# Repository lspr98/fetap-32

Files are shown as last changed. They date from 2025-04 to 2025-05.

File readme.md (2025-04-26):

# FeTAp-32

<picture>
  <source srcset="doc/images/fetap32-logo-text-black.svg" media="(prefers-color-scheme: light)"/>
  <source srcset="doc/images/fetap32-logo-text-white.svg"  media="(prefers-color-scheme: dark)"/>
  
</picture>

## Description
FeTAp-32 is an open-source project that turns an old FeTAp 611-2 (Fernsprechtischapparat) into a voice assistant device through an ESP32-C3 and [esphome](https://esphome.io/).

## Features
- Fully functional rotary dial with customizable automations for each digit
- Power delivery through USB-C, network connectivity through Wifi 2.4 GHz
- Enhanced privacy as microphone is only active if handset is lifted-up
- No wake-word detection required, the assistant is started when the handset is picked up
- Modular and customizable through esphome

<p align="middle">
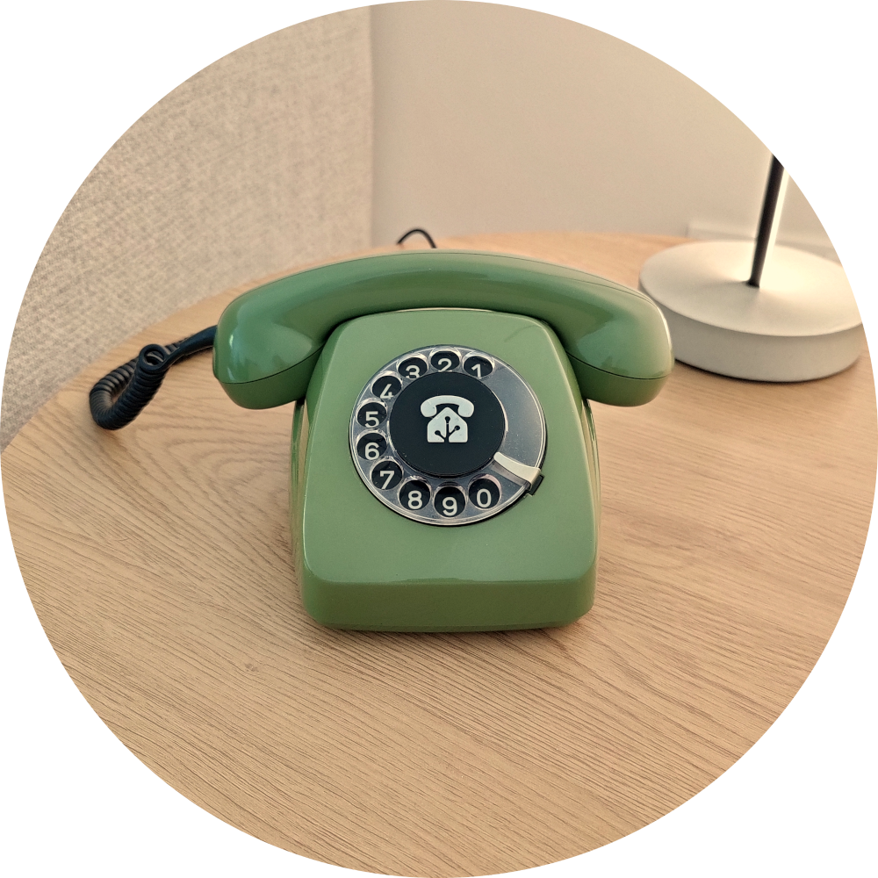
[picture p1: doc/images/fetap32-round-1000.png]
  
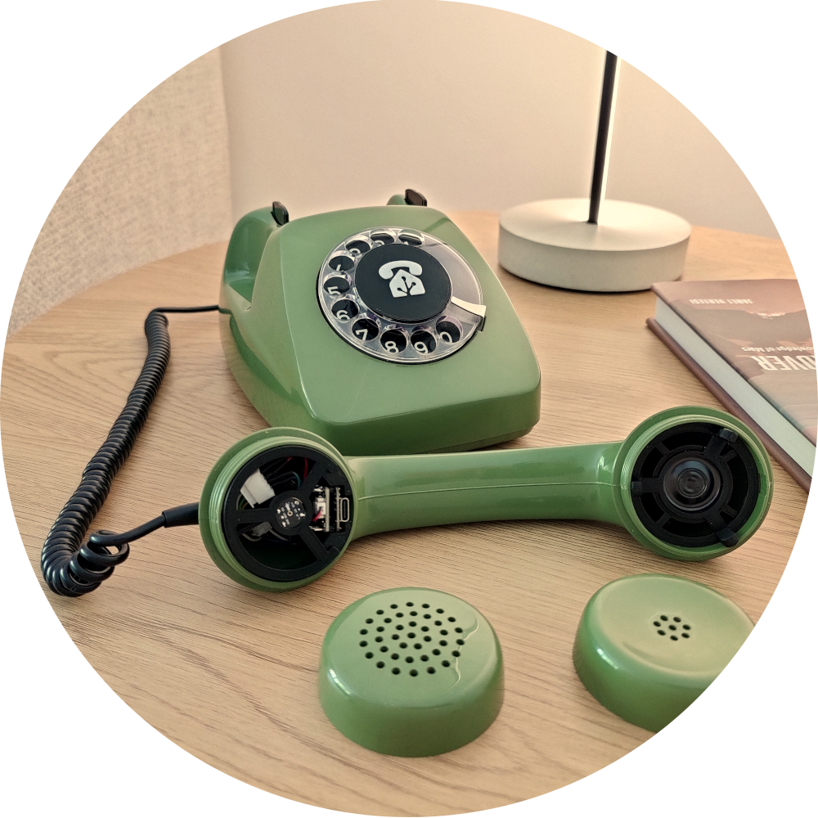
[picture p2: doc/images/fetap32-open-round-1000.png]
   
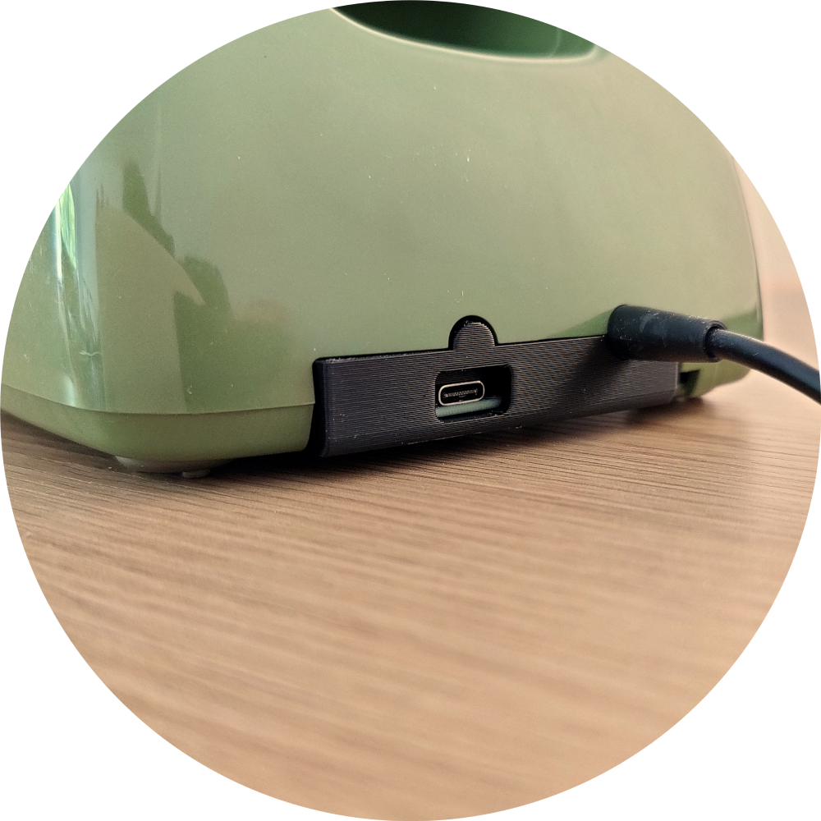
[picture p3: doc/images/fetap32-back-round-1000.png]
  
</p>

## Building instructions (Hardware and Software)
The manual can be found [here](doc/manual/manual.pdf)

## Disclaimer and warning
Recreating this project involves handling dangerous things like soldering irons and 3D-printers. For legal reasons, handling these things should only be done by an expert. I am not responsible for any damage to you, your telephone or your surrounding. Read through the complete manual to decide if you feel comfortable building the project.

## Required Tools
- 3D-printer
- soldering iron
- connector crimping kit (see BoM, optional but recommended)

## Bill of Materials (BoM)
The following items are necessary to build the FeTAp-32. Items marked with a (*) at the beginning do not need to be the exact listed item but may be replaced with something else. Sourcing links are included for people based in germany (those are the shops where I got the items from).

|Item|Amount|Description|Comment|Sourcing (DE)|
|---|---|---|---|---|
|FeTAp 611-2|1|the telephone|Commonly found on kleinanzeigen for cheap. Doesn't have to be functional as the ESP will replace the PCB.|-|
|Seeed Xiao ESP32C3|1|Modem and microcontroller|-|[Botland](https://botland.de/wifi-und-bt-module-esp32/21859-seeed-xiao-esp32-c3-wlan-bluetooth-seeedstudio-113991054.html) [Reichelt](https://www.reichelt.de/de/de/shop/produkt/xiao_esp32c3_wifi_bt-358356?search=esp32c3&)|
|Adafruit USB Type-C Breakout Board (ADA4090)|1|port for power over USB-C|-|[Berrybase](https://www.berrybase.de/adafruit-usb-type-c-breakout-board-downstream-verbindung)|
|Stranded Wire|~2m|wire to connect the components with each other|I recommend stranded wires and getting multiple colors to make it easier. The wires I used were multi-stranded with 0.14mm^2 diameter (approx. 25 AWG)|[Reichelt](https://www.reichelt.de/de/de/shop/produkt/kupferlitze_isoliert_10_m_1_x_0_14_mm_blau-10292)|
|INMP441 MEMS Microphone|1|digital microphone to capture voice commands|Optional, if you don't want voice assistant capabilities (e.g. only want to use the rotary dial)|[Berrybase](https://www.berrybase.de/inmp441-mems-omnidirektionales-mikrofonmodul-i2s-interface)|
|*Adafruit I2S Amplifier (ADA5769)|1|amplifier for the handset speaker|Optional, if you don't need audio output. There is also a version without SD-Card slot (ADA5770) that should also work.|[Botland](https://botland.de/mp3-wav-ogg-midi-player/23827-audio-bff-add-on-3w-i2s-audio-verstarker-modul-fur-qt-py-und-xiao-adafruit-5769.html) [Berrybase](https://www.berrybase.de/adafruit-audio-add-on-fuer-qt-py-und-xiao)|
|YD27 0.5W 8 Ohm speaker|1|speaker for audio feedback from voice assistant|Optional, if you don't need audio output.|[Botland](https://botland.de/analoge-lautsprecher/3471-lautsprecher-yd27-05w-8ohm-27x5mm-5903351245876.html)|
|Adafruit Molex PicoBlade cable|1|connector and cable for speaker and I2S amplifier|Optional, if you don't need audio output.|[Berrybase](https://www.berrybase.de/adafruit-molex-picoblade-kabel-2-polig-200mm-1.25mm-pitch-reibungsverriegelung)|
|*JST-XH 5-Pin Male and Female connectors|1|connector for microphone and esp|Optional, if you don't want to use a microphone or directly solder the wires together|[Amazon](https://www.amazon.de/SOMELINE%C2%AE-Crimpzange-Stecker-JST-XH-EI-Serie/dp/B0C8N8JBDC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)|
|*JST-XH 4-Pin Male and Female connectors|2|connectors for handset, housing and esp|Optional, if you want to directly solder the wires together|see above|
|*JST-XH 2-Pin Male and Female connectors|3|connectors for power, rotary-dial-sensor and handset-sensor|Optional, if you don't want to use a microphone or directly solder the wires together|see above|

Apart from the items listed above, you will need common consumables like shrink tubing, solder and 3D-printer filament.

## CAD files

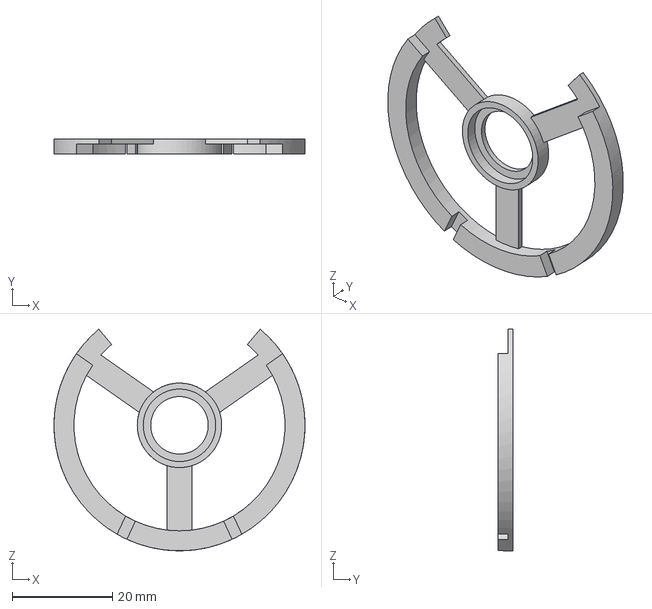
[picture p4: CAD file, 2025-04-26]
hardware/Esp_Brace v1.step
50.2 x 3.00 x 44.3 mm

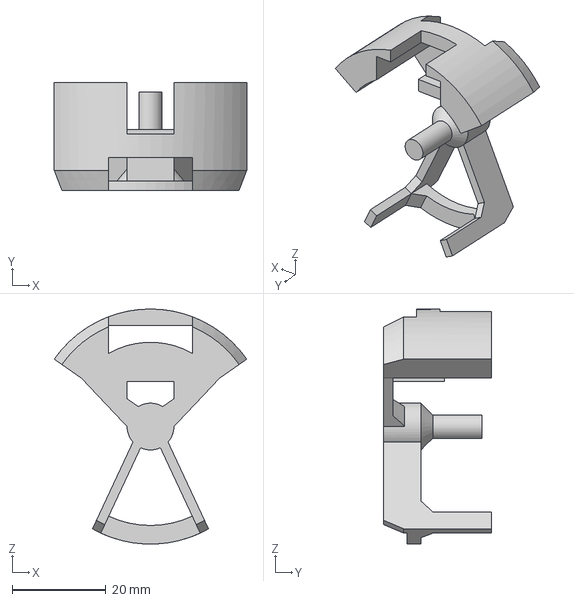
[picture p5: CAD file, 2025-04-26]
hardware/Esp_Insert v1.step
41.1 x 23.0 x 50.2 mm

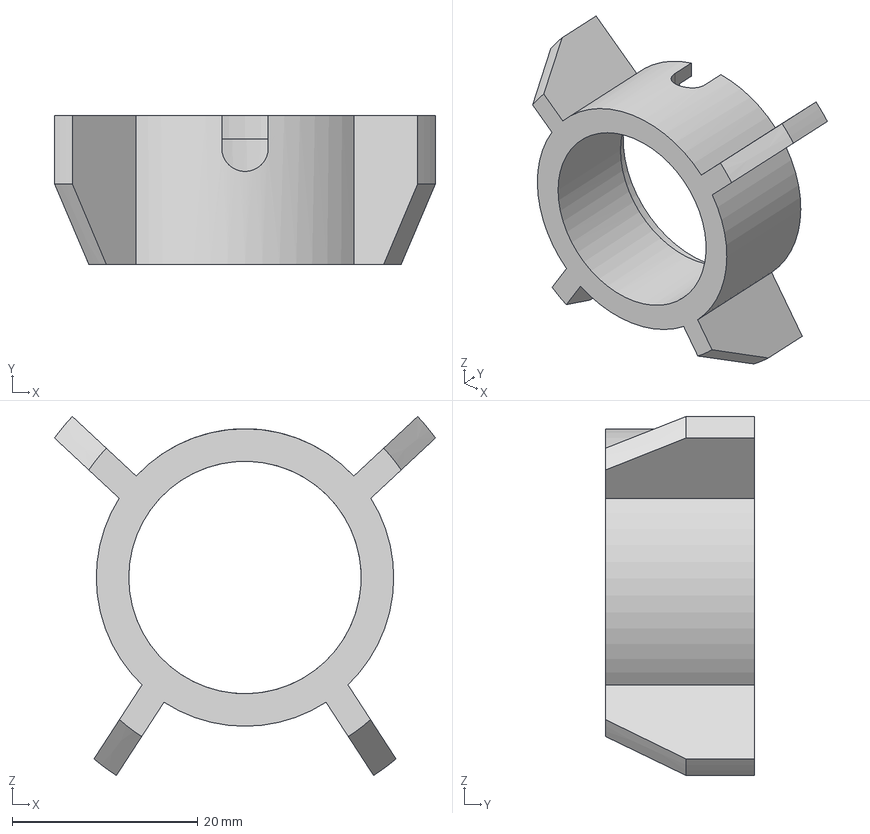
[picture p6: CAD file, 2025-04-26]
hardware/Speaker_Insert v10.step
41.0 x 16.0 x 38.6 mm

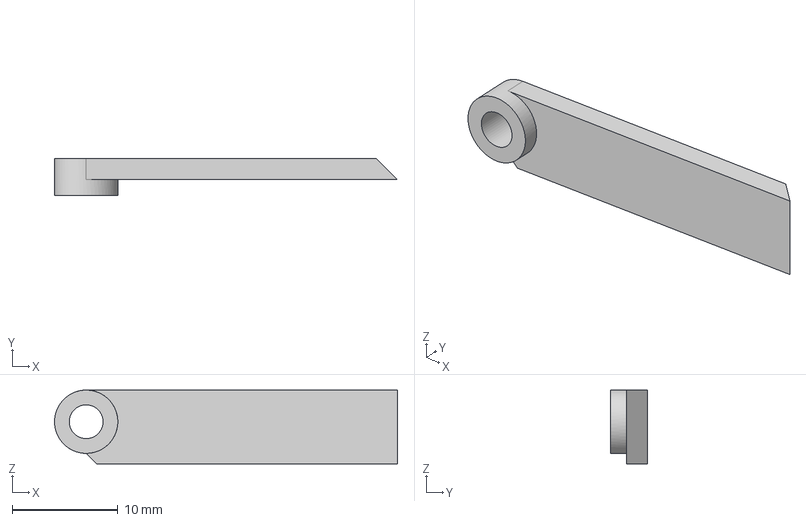
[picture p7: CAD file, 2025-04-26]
hardware/Connector_Brace v3.step
32.5 x 3.50 x 7.00 mm

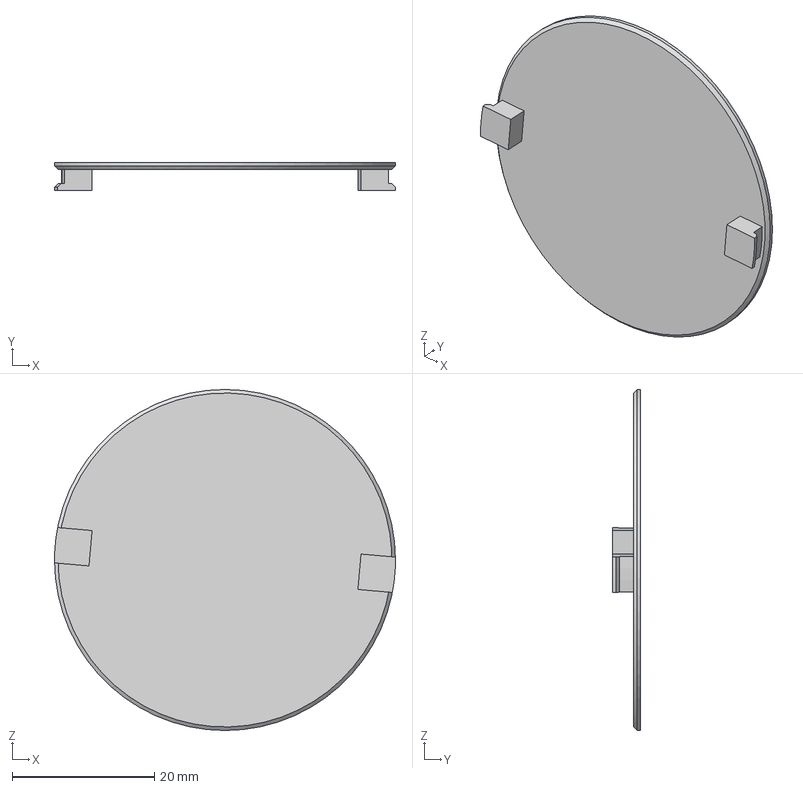
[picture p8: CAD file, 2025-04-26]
hardware/Emblem_Template v2.step
48.0 x 4.00 x 48.0 mm

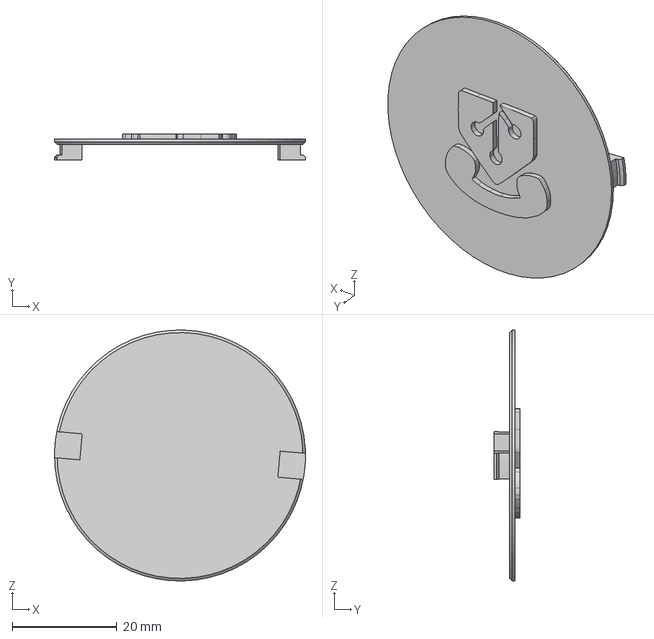
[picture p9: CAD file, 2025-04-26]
hardware/Emblem_Fetap32 v4.step
48.0 x 5.00 x 48.0 mm

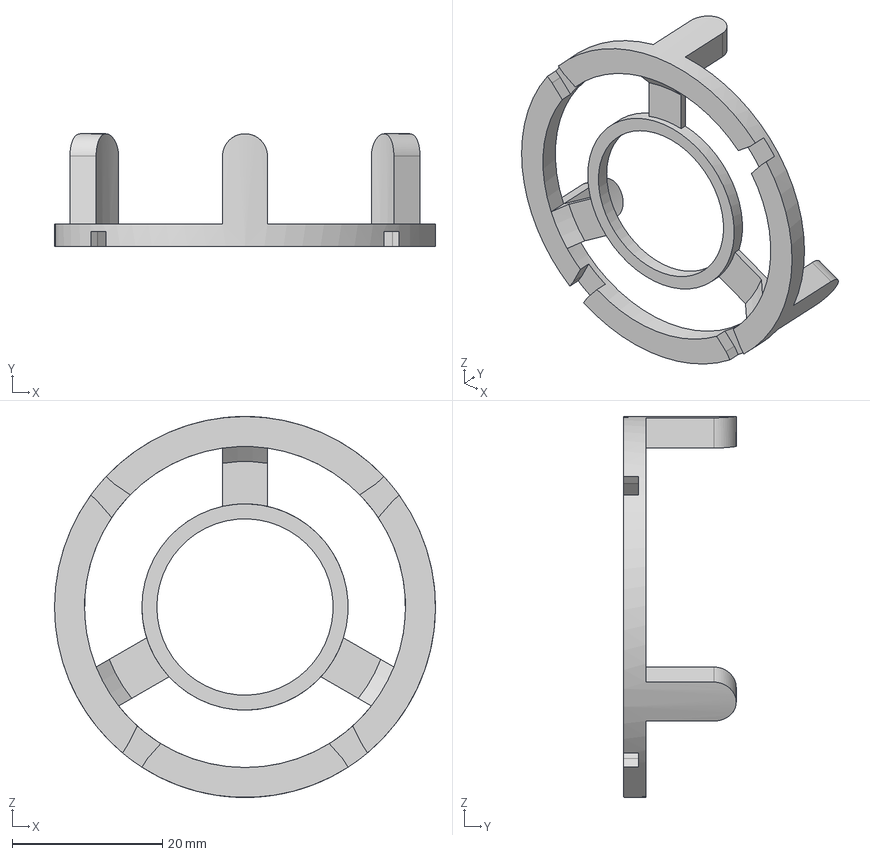
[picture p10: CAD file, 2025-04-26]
hardware/Speaker_Brace v8.step
50.8 x 15.0 x 50.8 mm

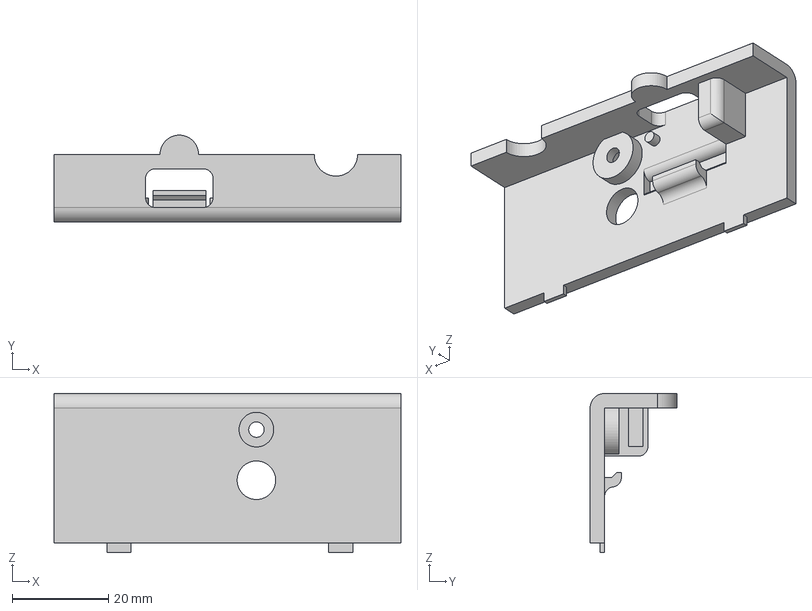
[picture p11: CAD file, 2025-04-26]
hardware/Connector_Cover v9.step
72.0 x 18.0 x 33.0 mm

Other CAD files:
hardware/Connector_Brace v3.stl
hardware/Connector_Cover v9.stl
hardware/Emblem_Fetap32 v4.stl
hardware/Esp_Brace v1.stl
hardware/Esp_Insert v1.stl
hardware/Speaker_Brace v8.stl
hardware/Speaker_Insert v10.stl

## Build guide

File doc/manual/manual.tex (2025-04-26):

\documentclass[]{article}

\usepackage{graphicx,wrapfig,hyperref}
\usepackage[top=2cm, bottom=2cm, right=2cm, left=2cm]{geometry}

%opening
\title{FeTAp-32 Build Manual}
\author{lspr98}

\begin{document}

\maketitle

\begin{abstract}
	This document guides you through the process of building your own \textit{FeTAp-32} from an old \textit{FeTAp 611-2}. Please read through the whole document before starting the build, to see what awaits you. These instructions are just my recommendations, feel free to tinker if you want to do something different.
	\newline
	\newline
	The FeTAp-32 is an ESP32C3 running ESPHOME with external components, sitting inside an old German retro rotary-dial telephone. Since its based on ESPHOME, it is modular and you may skip components that you do not want or add your own customizations. Each component (speaker, microphone, rotary-dial, etc...) has its own section in the manual. Optional components are marked with \textit{(optional)} in the section title.
	\newline
	\newline
	If a component requires 3D-printed parts, they are found as the first step of the sub-chapter. You can of course print them all together once you have decided what features you want to include. All 3D-printed parts are found in the \textit{hardware} folder of the repository, both as \textit{.step} and \textit{.stl} files. The parts were designed in such a way that no additional screws or nuts are required, which sometimes came at the cost of ease-of-assembly. It is however definitely possible to assemble the whole device without a second person.
	\newline
	\newline
	The manual is divided into two sections: the first section deals with building the hardware, the second is concerned with the software (building, flashing, adding to home assistant, etc...).
\end{abstract}

\tableofcontents

\section{Hardware}
\subsection{USB-C port installation}
\subsubsection{3D-printed parts}
\begin{minipage}[t]{0.4\linewidth}
	\vspace{0pt}
	Print \textbf{Connector\_Cover v9.stl} and \textbf{Connector\_Brace v3.stl} using a filament of your choice (mine is printed out of PLA+). Orient the parts as shown in the picture. \textbf{Enable support everywhere}. You may use \textbf{0.3mm layer height} to speed up the print.
\end{minipage}
\hfill
\begin{minipage}[t]{0.5\linewidth}
	\vspace{0pt}
	
\end{minipage}

\subsubsection{Opening the telephone}
\begin{minipage}[t]{0.4\linewidth}
	\vspace{0pt}
	Turn the telephone on its back. Verify that the telephone actually is a FeTAp 611-2. There are 3 screws securing the housing (green) and one screw securing the port cover (red), see first image. The housing screws may be covered by seals to prevent modifying the telephone. In that case you need to remove the seals (\textbf{this will void your warranty}).
	\newline
	\newline
	Next, unscrew the port cover screw (red) and remove the port cover (second image). Unplug any cable that is plugged in (third image). Be careful when removing the cables: they have a little notch in the rubber-end that acts as as stress-relief. You need to gently lift the rubber-part before pulling the plug.
	\newline
	\newline
	Finally, unscrew the 3 housing screws (green) and remove the housing.
\end{minipage}
\hfill
\begin{minipage}[t]{0.5\linewidth}
	\vspace{0pt}
	
	
\end{minipage}

\subsubsection{Removing the PCB}
\begin{minipage}[t]{0.4\linewidth}
	\vspace{0pt}
	Unplug the 3 plugs (red) and unscrew the two screws (green) next to the handset mechanism. We will later re-install the PCB so don't lose the two screws!
	\newline
	\newline
	Afterwards, carefully slide the PCB towards the front of the telephone and lift the PCB at an angle to remove it. The backside of the PCB and the two screws are shown in the second picture
\end{minipage}
\hfill
\begin{minipage}[t]{0.5\linewidth}
	\vspace{0pt}
	
	
\end{minipage}

\subsubsection{Making room for the USB-C board}
\begin{minipage}[t]{0.4\linewidth}
	\vspace{0pt}
	The back of the base-plate needs to be adjusted slightly to make room for the USB-C breakout board.
	\newline
	\newline
	A small area needs to be cut-off (marked in red on first image). Be careful not to break the back of the base-plate.
	\newline
	\newline
	The result should look similar to the second image.
\end{minipage}
\hfill
\begin{minipage}[t]{0.5\linewidth}
	\vspace{0pt}
	
	
\end{minipage}

\subsubsection{Preparing the USB-C board}
\begin{minipage}[t]{0.4\linewidth}
	\vspace{0pt}
	Prepare two cables of approx. 10cm length. Crimp a 2-pin JST-XH female connector to one end and solder the other ends to the \textbf{GND} and \textbf{VBUS} pin holes.
	\newline
	\newline
	Preferably, use a black cable for \textbf{GND} and a red cable for \textbf{VBUS}. The connector you just crimped will supply your FeTAp-32 with 5V.
\end{minipage}
\hfill
\begin{minipage}[t]{0.5\linewidth}
	\vspace{0pt}
	
\end{minipage}

\subsubsection{Installing the new port cover}
\begin{minipage}[t]{0.4\linewidth}
	\vspace{0pt}
	Slot the USB-C board into Connector\_Cover v9.stl as shown in the first picture. The USB-C board should sit evenly on the 3D-printed part.
	\newline
	\newline
	Next, use Connector\_Brace v3.stl and the port cover screw from the original port cover to secure the USB-C board as shown in the second picture. The Connector\_Brace v3.stl can only be installed in one direction.
	\newline
	\newline
	Thread the connector and cable that you soldered to the USB-C port through the opening in the back of the base-plate and secure the new port cover with the port cover screw. The result should look similar to the third picture.
	\newline
	\newline
	Finally, verify that you can plug and unplug a USB-C cable without the USB-C board coming loose and that the USB-C plug sits evently on the port cover (fourth picture).
\end{minipage}
\hfill
\begin{minipage}[t]{0.35\linewidth}
	\vspace{0pt}
	
	
	
	
\end{minipage}

\subsection{Handset preparation}

\subsubsection{Removing the old electronics}
\begin{minipage}[t]{0.4\linewidth}
	\vspace{0pt}
	Verify that the handset is already disconnected from the telephone, which was part of the previous section.
	\newline
	\newline
	Unscrew the microphone and speaker covers. Remove the old microphone and speaker as well as their rubber fittings (first picture).
	\newline
	\newline
	Unplug the microphone and speaker and pull the speaker wires through the handset such that all wires are hanging out at the bottom of the handset (second picture).
\end{minipage}
\hfill
\begin{minipage}[t]{0.5\linewidth}
	\vspace{0pt}
	
	
\end{minipage}

\subsubsection{Crimping the handset connectors}
\begin{minipage}[t]{0.4\linewidth}
	\vspace{0pt}
	There should be four wires running through the handset cord, colored brown, white, green and yellow.
	\newline
	\newline
	I used \textbf{brown for ground} (GND), \textbf{white for 5V} (VBUS), \textbf{green for the handset-sensor pin} and \textbf{yellow for the rotary-dial sensor pin}. If you decide to use a different pin-out, make sure to accommodate for the changes in all other steps as well!
	\newline
	\newline
	Crip a 4-pin JST-XH female connector to each side of the handset cord (first and second picture). You don't necessarily need to use the same pinning order on the connectors as long as all pins are connected correctly to the ESP in the end.
\end{minipage}
\hfill
\begin{minipage}[t]{0.5\linewidth}
	\vspace{0pt}
	
	
\end{minipage}

\subsubsection{Reconnecting the handset}
\begin{minipage}[t]{0.4\linewidth}
	\vspace{0pt}
	Unscrew the 3D-printed port cover again and re-insert the handset cable into its slot as shown in the first picture. Note that there is a little ridge in the rubber end that acts as a stress-relief for the cord.
	\newline
	\newline
	Make sure to pull the JST connector through the opening in the back of the base-plate and re-screw the 3D-printed port cover on. The result should be similar to the second picture.
\end{minipage}
\hfill
\begin{minipage}[t]{0.5\linewidth}
	\vspace{0pt}
	
	
\end{minipage}

\subsection{Rotary-Dial-Sensor preparation (optional)}
The rotary-dial sensor is optional but highly recommended, as it basically adds 10 individual virtual buttons through the numbers that can be dialed. It is also comparably low effort as you only need to crimp a connector. Its also very satisfying to trigger actions via the rotary-dial.
\subsubsection{Crimping the rotary-dial connector}
\begin{minipage}[t]{0.4\linewidth}
	\vspace{0pt}
	The rotary-dial has a 4-pin connector that we previously unplugged from the PCB. We only require the yellow and green wires. 
	\newline
	\newline
	Remove them green and yellow wires from the connector as shown in the first picture. Cut off the old metal contacts from these two wires and leave as much wire as possible to have room for error. Crimp a 2-pin JST-XH female connector to the yellow and green wire as shown in the second picture. \textbf{The pin order does not matter}, as it is basically just a contact that opens and closes in a certain pattern if the dial is spinning.
\end{minipage}
\hfill
\begin{minipage}[t]{0.5\linewidth}
	\vspace{0pt}
	
	
\end{minipage}

\subsection{Handset-Sensor preparation (optional)}
The handset-sensor senses if the handset is picked-up or put-down. It is optional but highly recommended, as it allows you to trigger custom actions or only activate the voice assistant (and microphone) if the handset is picked-up, removing the need for any wake-word detection.
\subsubsection{Hooking into the handset-sensor mechanism}
\begin{minipage}[t]{0.4\linewidth}
	\vspace{0pt}
	The handset-sensor uses a spring-loaded contact that opens when it is pressed down (e.g. the handset is placed on top of the telephone). We need to attach two wires to be able to sense when that contact opens or closes. The PCB should already be removed from previous steps.
	\newline
	\newline
	Prepare two wires, each approx. 20cm in length and crimp a 2-pin JST-XH female connector to them (see first picture).
	\newline
	\newline
	Next, solder the two wires to the PCB as shown in the second picture. Make sure you do not bridge any other contacts while soldering. 
\end{minipage}
\hfill
\begin{minipage}[t]{0.5\linewidth}
	\vspace{0pt}
	
	
\end{minipage}

\subsubsection{Function check (optional)}
\begin{minipage}[t]{0.4\linewidth}
	\vspace{0pt}
	Use a multimeter and measure the resistance between the two wires you just soldered to the PCB.
	\newline
	\newline
	Depending on the wear of your phone, the resistance should be close to zero when the handset-sensor is not pressed. In the first picture you can see my multimeter showing $0.8 \Omega$ when I am not pressing the contact down.
	\newline
	\newline
	If the handset-sensor is pressed, the multimeter should show O.L. (open loop), meaning the contact open (see second image).
\end{minipage}
\hfill
\begin{minipage}[t]{0.5\linewidth}
	\vspace{0pt}
	
	
\end{minipage}

\subsubsection{Installing the PCB}
\begin{minipage}[t]{0.4\linewidth}
	\vspace{0pt}
	It is now time to put the PCB back into the telephone. \textbf{Be careful not to pinch the two wires you just soldered}. Route them past the two mounting holes and use the little ridge on one side of the PCB for cable management as shown in the first picture.
	\newline
	\newline
	Slot in the PCB at an angle and secure it using the two screws next to the handset-sensor mechanism. \textbf{Make sure not to pinch any other cables too!}. If you did not skip any optional steps, you should end up with something similar to the second picture: There are four JST plugs hanging loose. Three 2-pin female plugs for power-input, rotary-dial-sensor and handset-sensor and one 4-pin female plug coming from the cord that attaches the handset.
\end{minipage}
\hfill
\begin{minipage}[t]{0.5\linewidth}
	\vspace{0pt}
	
	
\end{minipage}

\subsection{Housing wiring}
\subsubsection{Housing cable harness}
\begin{minipage}[t]{0.4\linewidth}
	\vspace{0pt}
	Next, you will have to create a connection between the connectors we just installed into the telephone. In the first picture, you can see a wiring diagram of how the components are supposed to be connected. If you did not install the optional components, you can of course ignore the respective connections.
	\newline
	\newline
	The yellow, green, white and brown wires are the cables coming out of the handset-cord, which you terminated by a 4-pin JST female connector (JST-F) previously. Two wires running through the cord are used to supply 5V (white) and GND (brown) to the ESP32 and the other two are for the rotary-dial-sensor (R) and handset-sensor (H).
	\newline
	\newline
	In the second picture you can see the cable harness I created for a \textit{full-build} (all optional components installed). Since we only installed JST-female connectors, \textbf{the cable harness only uses JST-male connectors}. \textbf{If you chose a different pinning on the cord JST female connector before, be sure the reflect your changes!}
	\newline
	\newline
	The \textbf{R-pin} is used for the rotary-dial sensor, and the \textbf{H-pin} is used for the handset-sensor. Since those two sensors are only contacts, switching the respective sensor-pin and the ground pin doesn't matter. \textbf{The cables for the harness are about ~10cm long. Be sure to use shrink-tubing to avoid any shorts.}
\end{minipage}
\hfill
\begin{minipage}[t]{0.5\linewidth}
	\vspace{0pt}
	
	
\end{minipage}
\subsubsection{Final checks and closing the housing}
\begin{minipage}[t]{0.4\linewidth}
	\vspace{0pt}
	Once the cable harness is finished, \textbf{connect all components using the harness as shown in the picture}. Cable management is not that important, as it will be hidden anyway. However, \textbf{be sure that no cables are blocking the handset-sensor mechanism!}
	\newline
	\newline
	Now is a good time to check if you wired everything up correctly before closing the housing. If you have a multimeter, measure the voltage between the brown and white wires on the handset-side. It should show approx. 5V when you connect a USB-C cable (which of course has to be connected to a PC or phone charging brick on the other end).
	\newline
	\newline
	If you prepared the handset-sensor, measure the resistance between the brown and green wires on the handset-side. It should be close to zero when the handset-sensor is not pressed and it should show O.L. (open loop) when you press the handset-sensor.
	\newline
	\newline
	If you prepared the rotary-dial-sensor, measure the resistance between the brown and yellow wires on the handset-side. It should be close to zero in idle. Now dial the number \textbf{1} (you have to turn the dial until you hit the metal limiter) and \textbf{very slowly} let it spin back by restricting its speed with your finger. You should see that the multimeter shows O.L. (open loop) or a very high resistance for a short amount of time.
	\newline
	\newline
	Finally, \textbf{place the housing back on the base-plate and secure it with the three housing screws on the back}. We are now finished with the housing and will continue with the handset (the fun part).
\end{minipage}
\hfill
\begin{minipage}[t]{0.5\linewidth}
	\vspace{0pt}
	
\end{minipage}

\newpage

\subsection{Speaker installation (optional)}
The speaker is technically optional, but required for a full voice-assistant experience. If you do not install a speaker, you will get no feedback from the assistant.

\subsubsection{3D-printed parts}
\begin{minipage}[t]{0.4\linewidth}
	\vspace{0pt}
	Since the new speaker is way smaller than the old one, a frame had to be designed to position the new speaker in the ear-piece compartment of the handset. You will need to print \textbf{Speaker\_Brace v8.stl} and \textbf{Speaker\_Insert v10.stl} with \textbf{supports enabled}. \textbf{Orient the parts as shown in the image}. Again, you can use any filament and I recommend 0.3mm layer height for faster printing. While the printer is running, you can already continue with the next step.
\end{minipage}
\hfill
\begin{minipage}[t]{0.5\linewidth}
	\vspace{0pt}
	
\end{minipage}

\subsubsection{Soldering the speaker connector}
\begin{minipage}[t]{0.4\linewidth}
	\vspace{0pt}
	Since the I2S amplifier uses a pico-blade connector, which I only managed to get pre-crimped (see BoM), we do not need to crimp this time. However, before soldering the wires to the speaker, \textbf{make sure the wires are at least 20cm long!} Otherwise, they will be too short to be connected to the amplifier later on. If they are too short, solder some extra length to them (don't forget shrink tubing) and finally \textbf{solder the wires to the speaker as shown in the image}.
\end{minipage}
\hfill
\begin{minipage}[t]{0.5\linewidth}
	\vspace{0pt}
	
\end{minipage}

\subsubsection{Installing the speaker}
\begin{minipage}[t]{0.4\linewidth}
	\vspace{0pt}
	Before installing the parts into the handset, take a closed look at the two 3D-printed parts. \textbf{Speaker\_Brace v8.stl} is meant to go on top of \textbf{Speaker\_Insert v10.stl} as shown in the first picture. Note that \textbf{they only fit together in a certain direction} (marked in red). 
	\newline
	\newline
	Take \textbf{Speaker\_Insert v10.stl} and place it inside the ear piece compartment as shown in the second picture. There is an opening in \textbf{Speaker\_Insert v10.stl} that is meant to be for the speaker cable, which should be aligned with the cable channel that runs through the handset. 
	\newline
	\newline
	Next, take the speaker and place it inside \textbf{Speaker\_Insert v10.stl} facing upwards with the cables running through the opening of \textbf{Speaker\_Insert v10.stl} into the cable channel (second picture). Verify that the speaker cable comes out at the lower end of the handset.
	\newline
	\newline
	Then place \textbf{Speaker\_Brace v8.stl} on top and make sure it is correctly aligned! (third picture)
	\newline
	\newline
	Make sure that the three arms of \textbf{Speaker\_Brace v8.stl} stick out 3-5mm from the edge of the threading as shown in the fourth picture. Verify that they are approximately equally high such that the speaker sits evenly. If they stick out too much or the speaker isn't even, the parts need repositioning. 
	\newline
	\newline
	Finally, you can screw the cover back on. The speaker is now ready!
\end{minipage}
\hfill
\begin{minipage}[t]{0.3\linewidth}
	\vspace{0pt}
	
	
	
	
\end{minipage}

\newpage
\subsection{Microphone preparation (optional)}
The microphone is only required if you want voice-assistant capabilities. You don't need it if you only want to use the rotary-dial for example.
\subsubsection{Soldering and crimping the microphone-side connections}
\begin{minipage}[t]{0.4\linewidth}
	\vspace{0pt}
	The microphone used is an INMP441 I2S digital microphone. There are five connections necessary to operate it: Ground, VCC (3.3V), data, word-select (or left/right clock) and bit-clock. 
	\newline
	\newline
	This means you need to \textbf{prepare 5 cables of approx. 5cm length and solder them to the GND, VCC, SD, WS and SCK pins of the microphone and crimp a JST-XH 5-pin female connector to the other end} as shown in the first picture. \textbf{Make sure that the cables are coming out of the back side of the microphone}. 
	\newline
	\newline
	The top side is the side with the small hole in the middle (microphone opening) and the microphone-symbol printed in silk-screen. I am using the following colour-code: \textbf{Black = GND, Red = VCC, White = SCK, Green = SD and Blue = WS}. You should \textbf{pull down the left/right selector pin by soldering it to the outer ground pad} of the microphone (red circle in second image).
	\newline
	\newline
	For now, that is all that has to be done for the microphone. Put it aside, we will use it later.
\end{minipage}
\hfill
\begin{minipage}[t]{0.5\linewidth}
	\vspace{0pt}
	
	
\end{minipage}

\subsection{ESP preparation}
\subsubsection{ESP pin-header soldering}
\begin{minipage}[t]{0.4\linewidth}
	\vspace{0pt}
	If your ESP did not come with pre-soldered pin headers, \textbf{start by soldering the pin headers to the back of the ESP}.
	\newline
	\newline
	If you installed the speaker, \textbf{solder the I2S amplifier board to the back of the ESP} as shown in the picture (ignore the wires for now). The port of the speaker connector should be on the same side as the USB-C port of the ESP.
\end{minipage}
\hfill
\begin{minipage}[t]{0.5\linewidth}
	\vspace{0pt}
	
\end{minipage}
\subsubsection{Handset cable harness}
\begin{minipage}[t]{0.4\linewidth}
	\vspace{0pt}
	Next, you will need to create the connection from the JST-XH 4-pin female connector of the cord to the ESP (shown on the left in the image). \textbf{The cables are approx. 5cm long and use the following colour-coding: Black = GND, Red = VBUS, Green = Handset-Pin, Blue = Rotary-Dial-Pin}. They are attached to a JST-XH 4-pin male connector to connect to the JST-XH 4-pin female connector coming out of the cord on the handset-side.
	\newline
	\newline
	If you prepared a microphone, you also need to create a connection for the JST-XH 5-pin female connector of the microphone to the ESP (shown on the right in the image). \textbf{These cables are also approx. 5cm long and use the same colour-coding as for the microphone: Black = GND, Red = VCC, White = SCK, Green = SD and Blue = WS}. Attach a JST-XH 5-pin male connector to them to connect it to the microphone.
\end{minipage}
\hfill
\begin{minipage}[t]{0.5\linewidth}
	\vspace{0pt}
	
\end{minipage}
\subsubsection{ESP connector soldering}
\begin{minipage}[t]{0.4\linewidth}
	\vspace{0pt}
	In this step, you will solder the handset cable harness to the ESP. Please familiarize with the wiring diagram in the first picture before you begin. The microphone connections only apply if you prepared a microphone. The handset-pin (H) and rotary-dial-pin (R) also only apply, if you prepared them earlier.
	\newline
	\newline
	I recommend soldering the microphone connector (right connector in diagram) first, as all its pins are on the same side. Secondly, solder the cord connector (left connector in diagram). The final product should look similar to the second and third picture.
\end{minipage}
\hfill
\begin{minipage}[t]{0.45\linewidth}
	\vspace{0pt}
	
	
	
\end{minipage}

\subsection{ESP installation}
\subsubsection{3D-printed parts}
\begin{minipage}[t]{0.4\linewidth}
	\vspace{0pt}
	The ESP and microphone are housed inside the microphone compartment of the handset. Similar to the speaker, they will be sitting in a 3D-printed frame. Please print \textbf{Esp\_Insert v1.stl} and \textbf{Esp\_Brace v1.stl} (found in the hardware folder) with \textbf{supports enabled}. \textbf{Orient the parts as shown in the image}. Again, you can use any filament and I recommend 0.3mm layer height for faster printing.
\end{minipage}
\hfill
\begin{minipage}[t]{0.5\linewidth}
	\vspace{0pt}
	
\end{minipage}
\subsubsection{Part Check}
\begin{minipage}[t]{0.4\linewidth}
	\vspace{0pt}
	The following steps will require: The handset, the two 3D-printed parts (\textbf{Esp\_Insert v1.stl} and \textbf{Esp\_Brace v1.stl}), the ESP with handset cable harness and (optionally) amplifier connected, the ESP antenna and optionally the microphone. Check the picture and verify that you got all parts ready.
	\newline
	\newline
	The following steps can be a bit tricky but are definitely possible with only two hands. Take your time.
\end{minipage}
\hfill
\begin{minipage}[t]{0.5\linewidth}
	\vspace{0pt}
	
\end{minipage}
\subsubsection{Connecting the ESP}
\begin{minipage}[t]{0.4\linewidth}
	\vspace{0pt}
	Slot the ESP into \textbf{Esp\_Insert v1.stl} as shown in the first picture. Make sure it is all the way in and the antenna connector is fully exposed.
	\newline
	\newline
	Connect the ESP antenna and (optionally) the microphone as shown on the second picture.
	\newline
	\newline
	Pull the JST connector of the cord through the hole in \textbf{Esp\_Insert v1.stl} and connect it to the ESP as shown in the third picture.
\end{minipage}
\hfill
\begin{minipage}[t]{0.45\linewidth}
	\vspace{0pt}
	
	
	
\end{minipage}
\subsubsection{Fitting the ESP}
\begin{minipage}[t]{0.4\linewidth}
	\vspace{0pt}
	Carefully push the ESP antenna into the cable channel in the handset while making sure to hold onto the (optional) speaker connector as shown in the first picture.
	\newline
	\newline
	Next, loop the microphone around the bottom of Esp\_Insert v1.stl and \textbf{pull the optional speaker connector through the smaller hole in Esp\_Insert v1.stl} as seen in the second picture.
	\newline
	\newline
	\textbf{Connect the speaker to the amplifier if present}.
	\newline
	\newline
	Push the whole assembly into the microphone compartment while \textbf{making sure to align the USB-C port of the ESP with the center-seam of the handset}. Also verify that the \textbf{cord cables are not pinched} between the handset and the assembly (red circle in second picture).
	\newline
	\newline
	If you connected a microphone, \textbf{push the microphone gently onto the middle arm} as shown in the third picture. The metal housing of the microphone sensor should be positioned right above the arm with no wires pinched in between.
\end{minipage}
\hfill
\begin{minipage}[t]{0.45\linewidth}
	\vspace{0pt}
	
	
	
\end{minipage}
\subsubsection{Securing the ESP}
\begin{minipage}[t]{0.4\linewidth}
	\vspace{0pt}
	Gently push down \textbf{Esp\_Brace v1.stl}, make sure to align it correctly as shown in the first picture.
	\newline
	\newline
	If you have a microphone, make sure the microphone stays centered and no cables are pinched by it. Check that the gap between the upper edge of \textbf{Esp\_Brace v1.stl} and the edge of the handset thread is not larger than 3mm. If it is, there may be cables pinched or the parts are positioned incorrectly.
	\newline
	\newline
	Finally, finish your build by screwing the cover for the mouthpiece back on. That's it! Your FeTAp-32 hardware is now finished!
\end{minipage}
\hfill
\begin{minipage}[t]{0.45\linewidth}
	\vspace{0pt}
	
	
\end{minipage}

\subsection{Emblem installation (optional)}
\subsubsection{3D-printed parts}
\begin{minipage}[t]{0.4\linewidth}
	\vspace{0pt}
	If you want to customize the appearance of your FeTAp-32, you can print a new cover emblem for the rotary dial to make people aware that this is not just a normal old rotary telephone.
	\newline
	\newline
	An emblem with the FeTAp-32 logo is included as \textbf{Emblem\_Fetap32 v4.stl} which you can use. Make sure you \textbf{enable support only on the build-plate}. I also added a filament colour change to make the logo stand out (see picture).
	\newline
	\newline
	There is also a file called \textbf{Emblem\_Template v2.step}, which is an empty emblem for you to customize with a 3D modelling program of your choice.
\end{minipage}
\hfill
\begin{minipage}[t]{0.5\linewidth}
	\vspace{0pt}
	
\end{minipage}

\subsubsection{Installing the emblem}
\begin{minipage}[t]{0.4\linewidth}
	\vspace{0pt}
	Use your two thumbs to rotate the original dial cover counter-clockwise (see first image).
	\newline
	\newline
	Afterwards, you should be able to just remove the cover (second image).
	\newline
	\newline
	To install the 3d-printed emblem, just reverse the steps and rotate it clockwise to lock it into place. Make sure the two clips left and right are both locked (third image).
\end{minipage}
\hfill
\begin{minipage}[t]{0.4\linewidth}
	\vspace{0pt}
	
	
	
\end{minipage}

\newpage

\section{Software}
\subsection{Configuration}
The ESP needs to connect to your network over wifi in order to communicate with Home-Assistant. To do that, you need to provide the SSID of your network (\textit{wifi\_ssid}) and the password (\textit{wifi\_password}). Edit the file \textbf{secrets.yaml} accordingly. 
\newline
\newline
You should also set an access point ssid (\textit{ap\_ssid}) and access point password (\textit{ap\_password}). The access-point settings are used to create a hotspot in case the FeTAp-32 can't connect to your network. 
\newline
\newline
Finally, you can also provide a password for over-the-air updates (\textit{ota\_password}), in case you want to modify the firmware without having to connect the FeTAp-32 to your PC again.

\subsection{Building the firmware}
Clone the repository to your PC and change into the root folder of the repository.
\newline
\newline
If you do not have esphome installed locally on your machine, follow the instructions on installing esphome locally: \href{https://esphome.io/guides/installing_esphome.html}{https://esphome.io/guides/installing\_esphome.html}
\newline
\newline
You should now have an active local virtual python environment (on ubuntu, this is indicated by e.g. \textit{(venv)} in front of your command line prompt, where \textit{venv} is the name of your environment) with esphome installed. You can then build the firmware by running the following command:
\begin{verbatim}
	esphome build fetap32.yaml
\end{verbatim}
If everything goes well, you should see an output that ends with
\begin{verbatim}
	INFO Successfully compiled program.
\end{verbatim}
Great, the firmware is now ready to be flashed onto the device.

\subsection{Flashing the firmware}
\begin{minipage}[t]{0.4\linewidth}
	\vspace{0pt}
	To flash the firmware, you need to directly connect the ESP with the computer using a USB-C cable. \textbf{Always make sure that the USB-c power port is unplugged before doing so.}
	\newline
	\newline
	To connect the ESP with a computer, simply unscrew the microphone cover of the handset and plug the USB-C cable in as shown in the first picture.
	\newline
	\newline
	Once the device is connected to your computer, run the following command:
	\begin{verbatim}
		esphome run fetap32.yaml
	\end{verbatim}
	You may be asked what upload option you would like to use. In that case, choose \textit{USB JTAG} by entering the corresponding option number (in my example, the USB JTAG option has number one, as seen in the second picture) and confirm by pressing enter.
	\newline
	\newline
	Once flashing completes, debug information from the ESP will be printed to the console and after a short while, it should connect to your wifi. Once it is connected, it will print the IP address that it got assigned (in my case $192.168.178.110$, see second image). Take note of the address your FeTAp-32 got, as we may need it to add it to Home-Assistant.
	\newline
	\newline
	The flashing process is now finished. You can unplug the USB-C cable from the ESP, screw the microphone cover back on and power the FeTAp-32 back on by plugging into the USB-C power port on the back of the device.
\end{minipage}
\hfill
\begin{minipage}[t]{0.5\linewidth}
	\vspace{0pt}
	
	
	
\end{minipage}

\subsection{Home-Assistant Setup}
\subsubsection{Adding the device}
\begin{minipage}[t]{0.4\linewidth}
	\vspace{0pt}
	Open your Home-Assistant dashboard and go to \textbf{Settings $>$ Devices \& services} and press \textbf{Add Integration} in the lower right corner (see first picture).
	\newline
	\newline
	Search for \textit{ESPHome} and select it. In the host field, enter the IP address of your FeTAp-32 (second picture). You can also try to use \textit{fetap32.local} instead, however, that may not work depending on how your network is configured.
	\newline
	\newline
	If Home-Assistant could reach your FeTAp-32, you should get a pop-up saying \textit{Success!}. Now select the area for your voice-assistant and press finish to finalize the setup (third picture).
	\newline
	\newline
	Your FeTAp-32 is now connected to Home-Assistant and ready to use. If you don't have a voice-assistant pipeline setup, you will need to do that first before being able to issue any voice commands (there are plenty of tutorials online). If you connected the rotary dial, try dialing in a number. It should briefly show the number value for the \textit{fetap\_rotary\_sensor} before switching back to $-1$.
\end{minipage}
\hfill
\begin{minipage}[t]{0.5\linewidth}
	\vspace{0pt}
	
	
	
	
\end{minipage}

\subsubsection{Rotary Dial Automation (optional)}
If you connected the rotary dial sensor, you can setup a custom automation for each number. On the FeTAp-32 device overview screen, click on the blue plus sign next to \textbf{Automations}.
\newline
\newline
Then select \textbf{Create New Automation}.
\newline
\newline
Press \textbf{Add Trigger} and select \textbf{Entity} and \textbf{State}. Search for the \textbf{sensor.fetap\_rotary\_sensor} entity and select it.
\newline
\newline
Press \textbf{Add Condition} and select \textbf{Entity} and \textbf{State}. Search for the \textbf{sensor.fetap\_rotary\_sensor} entity and select it. In the \textbf{State} field, type in the number for that automation (0 - 9).
\newline
\newline
Press \textbf{Add Action} and configure the action you want to perform when that number is dialed. Once you are finished, the automation should look something like the image below. I configured the automation to turn on my light named \textbf{Trinity 2} when I dial the number 5. Finish your automation setup by pressing \textbf{Save}.



\end{document}

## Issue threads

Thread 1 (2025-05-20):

Siemens build log and questions

emorytaylor, 2025-05-20:
I was very motivated by your build and impetuously bought what I assumed would be an identical phone online but turns out is a Siemens varient. I immediately took the body off and it seemed to confirm that even though it was labeled 611 on the exterior, The pcb was labeled 611-2 but the pcb itself and some internal components seem different but with the same basic wiring. There's also a plastic clip that dropped out which I couldn't identify where it lives.  I haven't taken apart the headset yet due to time but I wanted to share it here if there are any gotchas I should be aware of. Thanks for your great write up!

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
<!-- Failed to upload "PXL_20250520_194922787.jpg" -->
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
<!-- Failed to upload "PXL_20250520_200958263.jpg" -->
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

lspr98, 2025-05-24:
Hey Emory,

having a 611-2 is not an issue. The only component on the PCB that is used is the handset contact-switch and the pins are the same as on the 611. To be sure, I recommend you use a multi-meter and verify that you got the correct pins (see section 1.4.2 of the manual).

The 4-pin rotary-dial plug and pinning is also identical to the 611.

The plastic pin that fell out is a cover for an accessory port at the back of the telephone. You can just slide it back in when re-assembling the phone to get a clean back cover :)

If you encounter any difficulties when fitting the 3D-printed parts into the handset, just reopen the issue and provide me with the dimensions so I can help you out.

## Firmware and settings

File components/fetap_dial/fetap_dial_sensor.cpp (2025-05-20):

#include "fetap_dial_sensor.h"

#include "freertos/FreeRTOS.h"
#include "freertos/timers.h"
#include "esphome/core/log.h"

namespace esphome {
namespace fetap {

static const char *const TAG = "fetap.dialsensor";
static const size_t TASK_STACK_SIZE = 2048;
static const ssize_t TASK_PRIORITY = 22;

static TimerHandle_t timer_handle;
static SemaphoreHandle_t rotary_dial_sampling_semaphore;
static TickType_t t_rotary_dial_interrupt;
static bool dialing_timeout_flag = false;

static void IRAM_ATTR rotary_dial_sensor_isr_handler(void* arg) {
    // Unlock task loop if we are currently not sampling
    if(t_rotary_dial_interrupt == 0) {
        t_rotary_dial_interrupt = xTaskGetTickCountFromISR();
        xSemaphoreGiveFromISR(rotary_dial_sampling_semaphore, NULL);
    }
}

static void timer_publish_handler(TimerHandle_t timer) {
    dialing_timeout_flag = true;
    xSemaphoreGive(rotary_dial_sampling_semaphore);
}

void FetapDialSensor::setup() {
    esp_err_t err;

    err = gpio_install_isr_service(0);
    if (err != ESP_OK) {
        ESP_LOGE(TAG, "Error starting ISR service: %s", esp_err_to_name(err));
        mark_failed();
        status_set_error();
        return;
    }

    // Configure the DIAL pin as input with internal pull-up which triggers an interrupt on rising edges
    // Due to the way the rotary dial is wired up, the signal will be LOW when the rotary dial contact
    // is closed (default state when nothing is dialed) and the signal will be HIGH when the rotary dial 
    // contact is open (happens in short pulses when the dial is spinning back into position).
    const gpio_config_t sensor_pin_cfg {
        .pin_bit_mask = static_cast<uint64_t>(1) << dial_pin_,
        .mode = GPIO_MODE_INPUT,
        .pull_up_en = GPIO_PULLUP_ENABLE,
        .pull_down_en = GPIO_PULLDOWN_DISABLE,
        .intr_type = GPIO_INTR_POSEDGE
    };

    err = gpio_config(&sensor_pin_cfg);
    if (err != ESP_OK) {
        ESP_LOGE(TAG, "Error configuring dial pin: %s", esp_err_to_name(err));
        mark_failed();
        status_set_error();
        return;
    }

    // Register interrupt handler for sensor pin
    err = gpio_isr_handler_add(dial_pin_, rotary_dial_sensor_isr_handler, (void*) dial_pin_);
    if (err != ESP_OK) {
        ESP_LOGE(TAG, "Error adding ISR handler: %s", esp_err_to_name(err));
        mark_failed();
        status_set_error();
        return;
    }

    // Create semaphore to synchronize task with interrupts from sensor pin
    rotary_dial_sampling_semaphore = xSemaphoreCreateBinary();
    xSemaphoreTake(rotary_dial_sampling_semaphore, 0);

    if (dial_timeout_) {
        timer_handle = xTimerCreate("dial_publish_timer", pdMS_TO_TICKS(dial_timeout_), pdFALSE, (void *) 0, timer_publish_handler);
    }

    // Start dial task
    xTaskCreate(FetapDialSensor::dial_task, "fetapdial_task", TASK_STACK_SIZE, (void *) this, TASK_PRIORITY,
                &task_handle_);

    ESP_LOGI(TAG, "Fetap Dial Task initialized successfully.");
}

void FetapDialSensor::dial_task(void *params) {
    FetapDialSensor * instance = static_cast<FetapDialSensor *>(params);

    while(1) {
        instance->task_loop();
    }
}

void FetapDialSensor::task_loop(void) {
    // Set last interrupt time to 0 to signal that we are currently not sampling
    t_rotary_dial_interrupt = 0;
    
    // Wait until user starts dialing a number or a timeout is triggered from a
    // previously dialed number. If a number was dialed, this will trigger the 
    // registered interrupt since the DIAL pin will be pulled up as soon as the
    // rotary dial contact opens. The interrupt will set t_rotary_dial_interrupt
    // to the time where the positive edge of the first impulse was detected and
    // unlock the semaphore so that the task can start with sampling.
    xSemaphoreTake(rotary_dial_sampling_semaphore, portMAX_DELAY);

    if (dialing_timeout_flag) {
        // User stopped dialing in digits. Publish the complete number.
        publish_number();
    } else {
        // User dialed a new digit. Sample the DIAL pin to determine the digit that was dialed
        sample_rotary_dial();
    }
    
    // Wait minimum time until next number can be dialed in
    vTaskDelay(pdMS_TO_TICKS(kNumberDialGapMilliseconds));
}

void FetapDialSensor::sample_rotary_dial(void) {
    const uint16_t tick_delay_closed{pdMS_TO_TICKS(kPulseClosedMilliseconds)};
    const uint16_t tick_delay_sample{pdMS_TO_TICKS(kSampleDelayMilliseconds)};

    // Initialize counter with -1 to detect if no pulses were detected
    int8_t counter{-1};
    for(; counter < 10; counter++) {
        bool pin_was_high{false};
        
        // Sample the DIAL pin kSamplesPerPulse time while we expect the contact to
        // be open (= pin is pulled HIGH through internal pull-up). We need to sample
        // multiple times per pulse as the mechanical contacts of over 50 year old
        // telephones might not be in the best shape and provide an unreliable signal.
        // At least one sample needs to be high to confirm the presence of a pulse.
        for (uint8_t sample_idx = 0; sample_idx < kSamplesPerPulse; sample_idx++) {
            pin_was_high |= gpio_get_level(dial_pin_);
            xTaskDelayUntil(&t_rotary_dial_interrupt, tick_delay_sample);
        }

        // All samples returned a closed contact -> there was no pulse, so don't
        // expect any follow-up pulses.
        if(!pin_was_high) {
            break;
        }

        // Time frame in which the contact is supposed to be open is finshed,
        // the conact will be closed for a short amount of time in which we
        // don't need to do anything.
        xTaskDelayUntil(&t_rotary_dial_interrupt, tick_delay_closed);
    }

    if (counter < 0) {
        // No pulses detected
        return;
    }

    // Convert pulses to the dialed digit as UTF-8 character
    const char dialed_digit = ((counter + 1) % 10) + 0x30;

    // Add new digit to number
    dialed_number_ += std::string(1, dialed_digit);

    if (dial_timeout_) {
        // Non-zero timeout is configured. Start timer to wait
        // for potential follow-up digits
        xTimerReset(timer_handle, 0);
    } else {
        // No timeout configured. Directly publish digit as state
        publish_number();
    }
}

void FetapDialSensor::publish_number(void) {
    // Publish dialed number as new state
    publish_state(dialed_number_);
    // Reset dialed number
    dialed_number_.clear();
    // Reset timeout flag
    dialing_timeout_flag = false;
}

}
}
